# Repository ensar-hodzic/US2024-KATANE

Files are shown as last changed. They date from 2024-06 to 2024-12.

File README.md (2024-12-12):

# Keep talking and nobody explodes IRL
This is a real life game inspired by the video game called **"Keep talking and nobody explodes"**. It is a college project for the Embedded systems class. 
It uses a variety of electrical components and 2 Raspberry Pico Pi W's that communicate via MQTT. The game consists of several small challenges that have to be completed in order
to defuse the so called "bomb". But if you make a mistake you get a strike, and if you go over the maximum amount of strikes the bomb explodes. The bomb also explodes if you go over
the set time limit.

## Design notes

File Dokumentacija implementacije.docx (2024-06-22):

# Dokumentacija implementacije

# 1. Uvod

Ovaj dokument pruža tehničko objašnjenje implementacije verzije igre "Keep Talking and Nobody Explodes" na Pi Pico W platformi. Igra uključuje nekoliko mini igara koje igrači moraju riješiti koristeći različite hardverske komponente.

# 2. Arhitektura Sistema

Arhitektura sistema uključuje dva Pi Pico W koji upravljaju različitim hardverskim komponentama. Komunikacija između komponenata i kontrolera ostvaruje se pomoću GPIO pinova, a između dva Pi Pica preko MQTT veze.

## 2.1 Dijagram Arhitekture

Arhitektura sistema se sastoji od sledećih komponenti:

- 2 Pi Pico W: Glavni kontroler sistema.
- 9 Buttona: Korišćeni za različite unose u igri.
- 2 LED DOT Matrix Displeja: Prikazivanje informacija vezanih za igru.
- Sedmosegmentni Displej: Prikaz preostalog vrijemena dok bomba ne eksplodira. OVDJE ZA ŠTA
- Potenciometar: Korišten za unos analognih vrijednosti.
- Enkoder: Korišten za unos rotacionih vrijednosti.
- Matrica Tastatura: Korišćena za unos različitih sekvenci.
- 4 LED diode: Signalizacija različitih stanja igre.

# 3. Komponente Sistema

Pi Pico W master je srce sistema, zadužen za upravljanje svim komponentama i izvršavanje logike igre. Pi Pico W slave služi za dodavanje još potrebnih pinova.

## 3.1 Buttoni

Četiri buttona su povezani na GPIO pinove Pico W i koriste se za unos različitih komandi u igri. Potrebni za igre:
Button press-1
Lavirint-4
Simon says-3
Morse kod-1

## 3.2 LED DOT Matrix Displeji

Dva LED DOT Matrix displeja su povezana na Pico W i koriste se za prikazivanje različitih informacija i stanja igre. Potrebne za igru:
Button press-1
Lavirint-1

## 3.3 Sedmosegmentni Displej

Sedmosegmentni displej je korišćen za prikazivanje brojeva i povezan je na GPIO pinove.
Potrebne za igru Decode.

## 3.4 Potenciometar

Potenciometar je povezan na analogni ulaz Pi Pico W i koristi se za unos analognih vrijednosti u igri. Potrebno za igru PotenciometarGame

## 3.5 Enkoder

Rotacioni enkoder je povezan na Pi Pico W i koristi se za unos rotacionih vrijednosti. Potrebno za igr Decode.

## 3.6 Matrična Tastatura

Matrična tastatura je povezana na GPIO pinove i koristi se za unos sekvenci. Potrebno za igru Pin kod.

## 3.7 LED diode

LED diode su povezane na GPIO pinove i koriste se za signalizaciju različitih stanja igre.
Potrebno za igre:
Simon says-3
Morse-1

## 3.8 RGB Dioda

ŠTA JE RGB DIODA

# 4. Logika i Algoritmi

Glavna logika se nalazi unutar naših main programa. Pošto imamo dva Pi Pico W uređaja oni će međusobno komunicirati da znaju ukoliko je već jedna igra u toku ili ne. Razlog korištenja dva Pico W jeste taj što za implementaciju datog projekta potrebno nam je bilo više pinova nego što se nalazi na smo jednom.

## 4.1 Button

Ovaj kod implementira igru na mikrokontroleru koristeći MAX7219 LED matriks displej, taster i timer. U igri se na LED displeju prikazuje određeni broj tačkica, a korisnikov zadatak je da pritisne i drži taster onoliko sekundi koliko je tačkica prikazano. Ako korisnik pritisne taster i drži ga ispravno, sve LED tačkice se upale. Ako korisnik pogriješi u brojanju ili predugo čeka, na displeju se prikazuje znak "X". Igra koristi timer za periodično ažuriranje prikaza tačkica i provjerava korisnikov unos kako bi se utvrdilo je li tačan ili ne.

## 4.2 Decoder

Ovaj kod koristi dekoder za upravljanje brojačem koji prikazuje vrijednost na 7-segmentnom displeju. Inicijalizacija uključuje definisanje ulaznih i izlaznih pinova, postavljanje tajmera za redovno osvježavanje prikaza brojeva, i podešavanje prekida za rukovanje ulaznim signalima sa dekodera (CLK i DT pinovi). Kada se okine prekid na CLK ili DT pinu, vrijednost brojača se ažurira: CLK prekid povećava broj, dok DT prekid smanjuje broj, u zavisnosti od stanja drugog pina. Kada korisnik pritisne taster (SW pin), provjerava se da li trenutna vrijednost brojača odgovara zadatom rješenju. Ako je tako, igra se završava sa uspjehom; u suprotnom, broj grešaka se povećava. Timer periodično osvježava prikaz na 7-segmentnom displeju, prikazujući trenutnu vrijednost brojača. Cilj igre je da korisnik pomoću dekodera postigne tačan broj i potvrdi ga pritiskom na taster.

## 4.3 Lavirint

Ovaj kod implementira igru lavirinta na mikrokontroleru koristeći MAX7219 LED matrični displej, taster dugmiće i tajmere. Inicijalizacija postavlja ulazne i izlazne pinove za taster dugmiće i SPI za komunikaciju sa MAX7219. Takođe se inicijalizuje i tajmer za periodično osvježavanje prikaza igrača na displeju. Generisanje lavirinta vrši se nasumično, kreirajući staze i zidove unutar 8x8 matrice. Postoje predefinisane početne i završne tačke lavirinta. Cilj igre je da korisnik upravlja igračem pomoću tastera kako bi stigao do završne tačke lavirinta bez sudara sa zidovima. Kada igrač stigne do završne tačke, igra se završava uspešno. Klasa ima metode za prikaz igrača na displeju, reakciju na pritisak tastera za kretanje u četiri moguća pravca (gore, dole, lijevo, desno), provjeru da li je igrač stigao do završne tačke, kao i metod za završetak igre kada se završna tačka dostigne. Dodatno, postoji statička metoda za kreiranje direktne putanje od početne do završne tačke lavirinta, kao i metoda za ispis trenutnog stanja lavirinta u konzoli. Ovaj kod omogućava interaktivnu igru na mikrokontroleru, koristeći jednostavne komponente poput LED matričnog displeja i tastera, demonstrirajući upotrebu periferija i logike programiranja za igre.

## 4.4 Pin kod

Klasa MatricnaGame omogućava interaktivnu igru sa matricom tastera na mikrokontroleru. U igri korisnik treba da unese određenu šifru koristeći matricu tastera, a cilj je da unese tačnu šifru prije nego što istekne vrijeme ili da ne napravi previše grešaka. Metoda generisiSifruMatricna postavlja trenutnu šifru koju korisnik treba da unese, na osnovu trenutnog stanja (state) koje se prosljeđuje. Metoda postaviSifru je postavljena kao reakcija na prekid (IRQ) koji se aktivira kada korisnik pritisne taster na matrici. Ona obrađuje unos korisnika, provjerava da li je unijeta šifra tačna ili greška, i na osnovu toga upravlja tokom igre. Konstruktor __init__ inicijalizuje sve potrebne parametre za igru: pinove za izlaz (izlazMatricna) koji kontrolišu redoslijed aktivnih redova matrice, pinove za ulaz (ulazMatricna) koji čitaju stanje tastera, i postavlja početno stanje igre na osnovu proslijeđenog stanja. Dodatno, postoje metode solved, get_sifra i get_strikes koje vraćaju informacije o trenutnom stanju igre (da li je igra rešena, trenutna šifra, broj grešaka). Ovaj kod demonstrira upotrebu tajmera, obrade prekida, rad sa digitalnim ulazima i izlazima na mikrokontroleru kako bi se implementirala jednostavna igra sa matricom tastera.

## 4.5 Morse kod

Ovaj kod implementira sistem za prikazivanje Morseovog koda pomoću LED diode i analognog senzora. Glavna klasa je Morse, koja pruža funkcionalnost za dekodiranje i prikazivanje unaprijed definiranih poruka u Morseovom kodu na LED diodi. Klasa sadrži statičke definicije za tablicu Morseovih znakova (morse) i definira različite Morseove poruke s pripadajućim frekvencijama i dužinama impulsa (code_book). U metodi __init__, kada se instancira objekt klase Morse, definira se željena poruka prema indeksu state u code_book, te se inicijaliziraju pinovi za LED diodu i analogni senzor. Poruka se zatim konvertira u niz impulsa (svjetla ili tame) koji će se prikazivati na LED diodi prema definiranom Morseovom kodu. Objekt prati stanje modulacije pomoću tri različita vrijemenska okidača (Timer): timer za periodično prikazivanje Morseovih impulsa na LED diodi, sampler za uzorkovanje analognog signala s frekvencijom definiranom u rate, te comparator za usporedbu uzorkovanog signala s ciljnim obrascem (definiranim u target). Metoda solved() provjerava je li modulacija riješena usporedbom sadržaja buffera (uzorkovani analogni signal) s ciljnim obrascem target. Ako je modulacija riješena (tj. ako je uzorkovani signal dovoljno blizak ciljnom obrascu), deaktiviraju se svi timski okidači (timer, sampler, comparator) i postavlja se zastavica self.solved na True. Ovaj sistem omogućuje strojno dekodiranje i prikazivanje Morseovog koda, koristeći analogne senzore za detekciju svjetlosnih uzoraka, čime se simulira komunikacija putem Morseovog koda preko svjetla.

## 4.6 Potenciometar

Ovaj kod implementira jednostavnu igru s potenciometrom na mikrokontroleru. Cilj igre je detektirati određenu vrijednost potenciometra koristeći ADC interfejs za pretvorbu analognog signala u digitalni oblik. Klasa Potenciometar ima konstruktor koji inicijalizira igru postavljanjem ciljane vrijednosti potenciometra, koja je unaprijed definirana u listi potencimetar_values. Ovisno o odabranom state parametru, odabire se odgovarajuća ciljna vrijednost. Igra koristi ADC objekt za čitanje trenutne vrijednosti s potenciometra, koji je spojen na određeni pin na mikrokontroleru. Timer (timerPot) se koristi za periodično izvršavanje funkcije PotenciometarGame, koja provjerava trenutnu vrijednost potenciometra. U metodi PotenciometarGame, trenutna vrijednost potenciometra se uspoređuje s ciljnom vrijednosti self.sifra. Ako je apsolutna razlika između očitane vrijednosti i ciljne vrijednosti manja od zadane tolerancije (eps), igra se riješava. Timer se zaustavlja, a zastavica self.solved postavlja na True, što označava da je igra završena uspješno. Metoda solved omogućuje vanjskom kodu da provjeri je li igra riješena, dok get_sifra vraća ciljanu vrijednost potenciometra za referencu ili prikaz korisniku. Ovaj sistem omogućuje jednostavno i automatizirano praćenje i rješavanje igre s potenciometrom, što može biti korisno u edukativnim ili demonstracijskim svrhama za učenje o radu s analognim senzorima i digitalnim sučeljima mikrokontrolera.

## 4.7 Simon says

Ovaj kod implementira igru "Simon Says" na mikrokontroleru, simulirajući igru u kojoj korisnik mora ponoviti uzorak paljenja i gašenja LED-ica prema predefiniranoj sekvenci. Klasa SimonSays ima konstruktor koji inicijalizira igru s dva lista pinova: button_pins za tastere koji se koriste za unos, i led_pins za LED-ice koje će se paliti i gasiti. Također prima listu code koja definira sekvencu koju korisnik mora ponoviti. LED-ice i tasteri inicijaliziraju se kao Pin objekti s odgovarajućim ulaznim (Pin.IN) I izlaznim (Pin.OUT) postavkama. code lista čuva sekvencu koju treba pogoditi. Za svaki taster postavlja se prekid (irq) koji reagira na uzlaznu (rising) promjenu signala, pozivajući button_handler metodu za obradu pritiska tastera. Implementirana je i debouncing logika kako bi se izbjegli lažni prekidi prilikom pritiska.
Periodični tajmeri (Timer) se koriste za upravljanje igrom:

- show_timer periodično pokreće funkciju turn_on_led kako bi se prikazala sekvencija svjetlosnih signala korisniku.
- prikazujSekvencu tajmer se koristi za periodično prikazivanje cijele sekvence LED-ica, s pauzama između sekvenci.

Metoda turn_on_led upravlja redoslijedom paljenja i gašenja LED-ica prema definiranoj sekvenci. Svaka LED-ica se pali i gasi prema trenutnom indeksu u code listi, omogućujući vizualno prikazivanje sekvence korisniku. Metoda checkInput provjerava unos korisnika nakon što je završena prikazana sekvencija. Ako korisnik ispravno ponovi sekvencu, ispisuje igra se završava i sve LED-ice se upale. Ako se pogriješi, korisniku se omogućuje ponovni pokušaj, a broj pogrešaka se povećava. Metoda ShowFailure koristi se za vizualni efekt u slučaju pogrešnog unosa, gdje se LED-ice brzo pale i gase kako bi signalizirale grešku prije ponovnog pokušaja. Ovaj kod pruža interaktivno iskustvo igre "Simon Says" na mikrokontroleru, koristeći LED-ice i tastere za unos, što omogućuje praktičnu primjenu u obuci ili demonstracijama za rad s digitalnim ulazima i izlazima.

## 4.8 Wirecutter

Klasa WireCutter simulira sistem za rezanje žica na mikrokontroleru. Inicijalizira se s izlaznim i ulaznim pinovima te listom pinova koji se smiju rezati. Parametar inOrder određuje redoslijed rezanja žica. Svi pinovi se inicijaliziraju kao objekti Pin za odgovarajuće ulazne ili izlazne funkcije. Izlazni pinovi se inicijalno postavljaju na on(). Tajmer timer periodično poziva funkciju CheckWires svakih 100 ms, koja provjerava stanje žica i detektira događaje na ulaznim pinovima. Svaki ulazni pin ima postavljen prekid (irq) na padajući rub signala, što aktivira metodu CheckWires za daljnju provjeru. Tajmer checker također periodično poziva funkciju checkSolved svakih 100 ms, koja provjerava jesu li sve žice označene u valid_to_cut listi već rezane. Metoda CheckWires upravlja logikom rezanja žica: provjerava redoslijed i ispravnost te bilježi pogreške ako žice nisu rezane prema očekivanjima. Metoda checkSolved provjerava jesu li sve žice iz valid_to_cut već rezane i postavlja zastavicu solved na True ako jesu. Ovaj kod pruža simulaciju upravljanja i praćenja rezanja žica na mikrokontroleru, koristeći digitalne ulaze i izlaze te periodično provjeravanje stanja sistema.

## 4.9 Pico W slave

Pico W slave uređaj inicijalizira globalne varijable za praćenje stanja igre, spremnosti (main_ready), trenutnog stanja (state) i izvršavanja igre (run). Definira i pinove za različite komponente: tipke i LED diode za igru Simon Says, matricu tastatura, potenciometar, pinove za Morseov kod, pin za igru s tasterom i pinove za igru s žicama. Pomoćna funkcija subscribe obrađuje MQTT poruke: postavlja main_ready kada je uređaj spreman, ažurira state kada stignu poruke o stanju igre, te zaustavlja igru na poruke o završetku igre ("win" ili "lose"). Funkcija check periodično provjerava stanje modula u igri, broji riješene module i prati greške. Informacije o broju grešaka i riješenim modulima šalje putem MQTT-a. Nakon uspostave Wi-Fi veze i MQTT klijenta, program čeka da glavni uređaj označi spremnost (main_ready). U glavnoj petlji čeka da glavni uređaj pokrene igru slanjem odgovarajuće MQTT poruke (run). Moduli igre se inicijaliziraju kao objekti različitih klasa (SimonSays, MatrixGame, Potenciometar, Morse, Button, Wires) s odgovarajućim parametrima. Glavni tajmer je postavljen da periodično poziva funkciju check kako bi pratio stanje igre tokom trajanja. U glavnoj petlji programa ispisuje se "game is running..." i čeka se signal o trajanju igre putem MQTT-a.

## 4.10 Pico W master

Pico W master uređaj koordinira upravljanje stanjem igre, komunikaciju putem MQTT-a i procese donošenja odluka. Ovisi o Pico W slave uređaju za dodatne GPIO pinove kako bi se komuniciralo s različitim komponentama igre. Slave uređaj rukuje specifičnim interakcijama u igri i šalje svoje stanje i napredak natrag master uređaju putem MQTT-a. Ova podjela zadataka omogućava distribuiranu obradu i efikasno upravljanje složenom logikom igre preko više uređaja. Pico W master uređaj inicijalizira globalne varijable za upravljanje stanjem igre i komunikaciju s drugim uređajima putem MQTT protokola. Navode se i pinovi koje Pi Pico W koristi za povezivanje s komponentama poput labirintskih tipki, displeja, enkodera i segmentnog displeja. Pomoćne funkcije uključuju subscribe, koja prati MQTT poruke za ažuriranje globalnih varijabli o prisustvu drugih igrača i stanju igre. Funkcija rgb_randomiser generira slučajne RGB vrijednosti za vizualne efekte ili indikacije u igri. Funkcija explode aktivira se kada igra završi zbog prekoračenja dozvoljenog broja grešaka ili rješenja svih modula. Zaustavlja glavni tajmer i šalje poruku "lose" putem MQTT-a. Funkcija check periodično provjerava riješene module i broj grešaka za donošenje odluke o završetku igre (pobjeda ili poraz). Funkcija publish_state objavljuje trenutno stanje igre putem MQTT-a, uključujući riješene module i maksimalan broj dopuštenih grešaka. Nakon postavljanja Wi-Fi veze i MQTT klijenta, program čeka registraciju slave uređaja i aplikacije na telefonu prije početka glavne igre. U glavnoj petlji igre, program inicijalizira početno stanje i maksimalan broj grešaka, periodično provjerava stanje igre sve dok se ne završi.

# 5. Zaključak

Ova dokumentacija pruža pregled ključnih tehničkih aspekata implementacije verzije igre "Keep Talking and Nobody Explodes" na Pi Pico W platformi. Detaljniji uvidi su dostupni u izvornom kodu projekta.

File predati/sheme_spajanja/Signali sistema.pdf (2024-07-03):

Signal | Tip | Opis
Pritisak tastera na tastaturi | Digitalni Ulaz | Registruje se pritisak na tastaturi adekvatno, i svaki 4 pritisak izaziva poređenje sa šifrom
Prozivka tastature | Digitalni Izlaz | Kada želimo provjeriti pritisak na nekom redu postavljamo adekvatni pin na HIGH.
Pritisak tastera za Button game | Digitalni Ulaz | Registruje se pritisak na taster i sve dok je pritisnut na LED displeju se prikazuje više i više tački. Kada se taster oslobodi vrši se poređenje broja prikazanih tačaka i ciljanog broja.
8x8 LED Displej | Digitalni Izlaz | Vršimo prikaz tački na 8x8 displeju. Komunikacija se vrši putem SPI. Ako je taster držan tačan broj sekundi onda se ekran potpuno potpunu, ako se desila greška prikazujemo “X”, inače je displej prazan.
Pritisak tastera za Simon Says | Digitalni Ulaz | Ako je taster pritusnut u vremenskom intervalu van prikaza LEDica, on će se registrovati. Svaki peti taster izaziva poređenje sa prikazanom sekvencom.
LEDice Simon Says | Digitalni Izlaz | Prikaz sekvence za simon says. Ako je modul riješen upaliti sve ledice.
Pritisak tastera za Labirint | Digitalni Ulaz | Svaki taster označava jednistven smjer kretanja u Labirintu, i njegovim pritiskom će se promijeniti pozicija igrača, ako je ot moguće, a ako bi igrač udario u zid labirinta on ostaje na mjestu i broj greški se inkrementira
8x8 LED Displej | Digitalni Izlaz | Displej prikazuje poziciju igrača trenutnu kao trepćuća

| | tačka, dok se izlaz prikazuje kao ispunjena tačka. Kada je labirint riješen ne treba ništa prikazati.
Pritisak Enkodera | Digitalni Ulaz | Pritiskom rotacionog enkodera se treba izvršiti poređenje brojača sa šifrom.
Pomjeranje Enkodera | Digitalni Ulaz | Pomjereanjem rotacionog enkodera se brojač inkrementira ili dekrementira u ovisnosti od smjera.
7seg Displej | Digitalni Izlazi | Prikaz trenutne vrijednosti brojača na displeju.
RGB dioda | Digitalni Izlaz | Prikaz stanja igre.

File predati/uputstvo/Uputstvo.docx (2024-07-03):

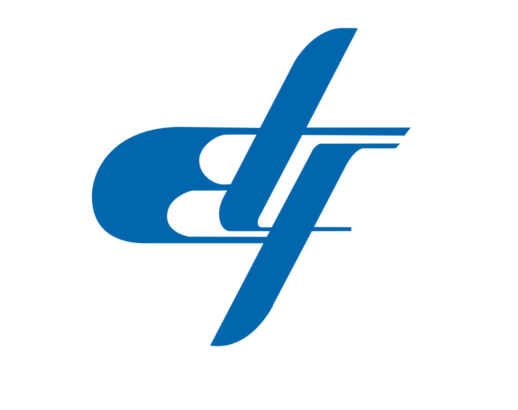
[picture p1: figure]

KAKO ZAUSTAVITI BOMBU???

UPUTSTVO ZA “KEEP TALKING AND NOBODY EXPLODES”

# 1. Sadržaj

# 2. O igri

Igra se sastoji od 2 igrača,jedan koji ima bombu pred sobom (deaktivator bombe)i drugi koji ima uputstvo (stručnjak).

Igrači imaju 3 minute da deaktiviraju bombu. Bomba se sastoji od 5 modula koji se moraju riješiti ispravno na način koji je opisan u uputstvu kako bi se bomba deaktivirala. Broj dozvoljenih grešaka je nasumičan između 0 i 3 i prikazan je na MQTT panelu.Ukoliko pređete preko dozvoljenog broja grešaka, igra završava.

Sretno!

# 3. Kako pokrenuti igru?

Potrebno je provjeriti postavke za konekciju na WiFi mrežu za naša dva mikrokontrolera unutar bombe. Oba mikrokontrolera je potrebno spojiti na računar i promijeniti postavke konekcije u config.py file-ovima. Također po potrebi promijeniti MQTT broker na neki po vašoj želji. Nakon toga se mogu priključiti oba mikrokontrolera na neki izvor napajanja.

Sljedeći korak jeste postaviti MQTT panele na nekoj MQTT Dashboard aplikaciji. Ukoliko želite koristiti naš kreirani panel, skinite aplikaciju IoT MQTT Panel (https://play.google.com/store/apps/details?id=snr.lab.iotmqttpanel.prod&hl=en), i u opciji Backup/Restore, restorati file pod imenom “KataneMQTTPanel.json”, i može se početi igrati.

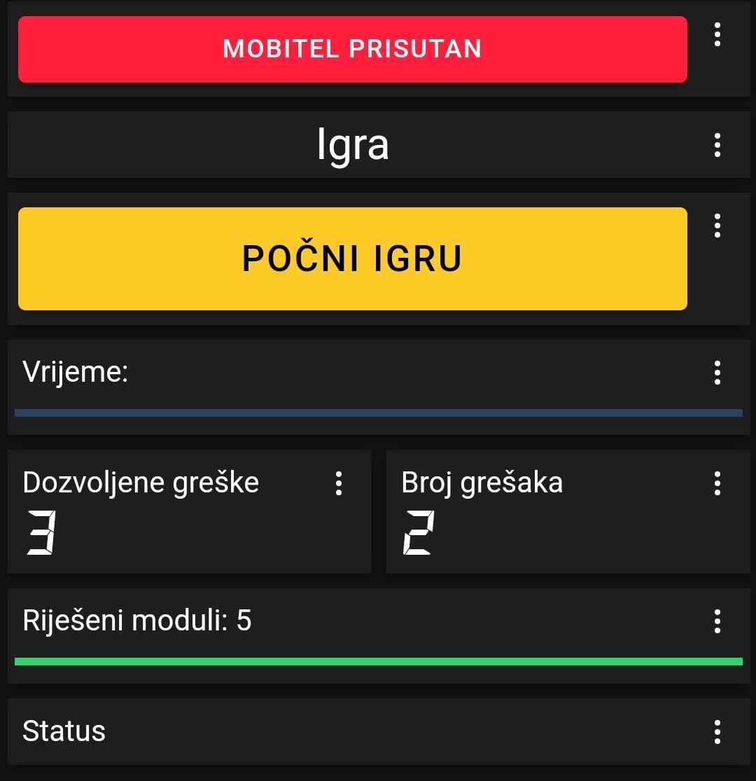
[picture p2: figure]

Topic | Tip | Payload | Opis
katane/app_present | Button | 1 | Prisutnost mobitela
katane/game_start | Button | 1 | Početak igre
katane/game_over | Text | | Kraj igre
katane/strikes | Text | | Broj grešaka
katane/solved | Text | | Broj riješenih modula
katane/game_state | JSON | max_strikes | Broj dozvoljenih grešaka
katane/time | Text | | Potrošeno vrijeme

Ukoliko ne želite koristiti naš panel, potrebno se pretplatiti na sljedeće topic-e.

Da bi započeli samu igru, potrebno je priključiti mikrokontrolere na izvor napajanja (kompjuter, powerbank, i sl.). Sačekati malo vremena da se spoje na mrežu. Na telefonu prvo je potrebno pritisnuti da dugme “Mobitel prisutan”i tek onda može se kliknuti dugme “Počni igru” kako bi igra počela.

# 4. MODULI

## 4.1 Modul: Simon Says

Modul se sastoji od 3 LED i 3 tipke, kako bi riješili ovaj modul, morate odigrati igru “Simon says”, što u biti znači da pratite šta god LED kažu da pritisnete. Pogriješite li sekvencu, napravili ste prekršaj.Ne možete unositi sekvencu dok se prikazuje.

## 4.2 Modul: Taster

Modul se sastoji od tastera i matrix displeja. Kako bi riješili ovaj modul, potrebno je pritisnuti i držati taster dok se odgovarajući broj tačaka na displeju ne pojavi. Uspješno rješavanje znači da je displej popunjen, dok neuspjeh se označi sa slovom X na displeju, i naravno još jednim promašajem. Odnos boje i broja tačaka se nalazi u tabeli ispod:

Boja | Broj tačaka
Nijedna | 2
Crvena | 3
Plava | 4
Ljubičasta | 5
Zelena | 6
Žuta | 7
Cyan | 8
Bijela | 9

## 4.3 Modul: Lavirint

Modul se sastoji od 4 tastera i matrix displeja. Kako bi riješili ovaj modul, potrebno je kretati se kroz lavirint dok se ne stigne do cilja. Tačka koja treperi predstavlja trenutnu poziciju. Drugi igrač govori prvom kuda da se kreće. Slike labirinta u odnosu na boju su ispod.

Boja | Lavirint

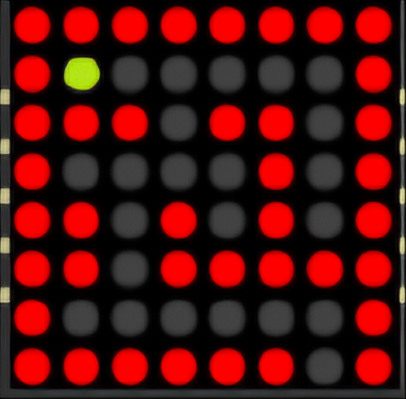
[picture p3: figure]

Nijedna

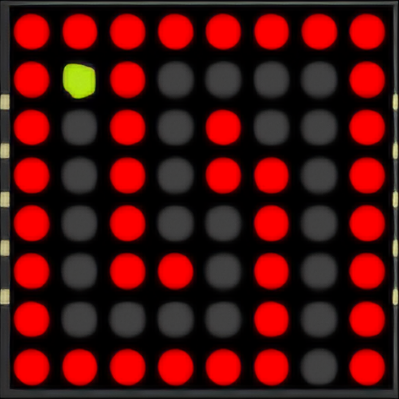
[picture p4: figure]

Crvena

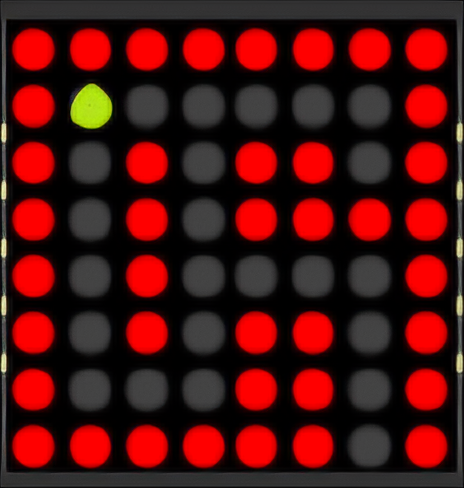
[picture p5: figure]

Plava

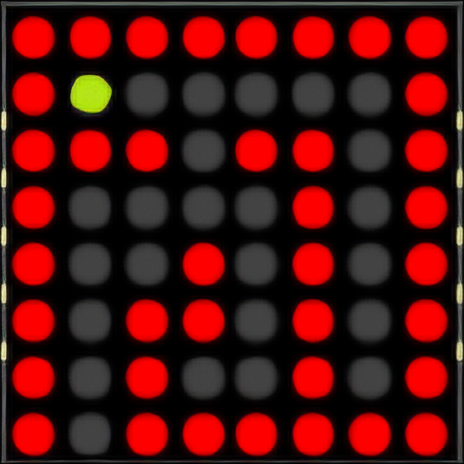
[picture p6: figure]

Ljubičasta

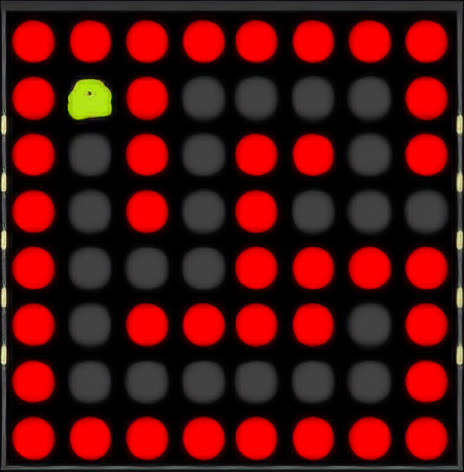
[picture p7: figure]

Zelena

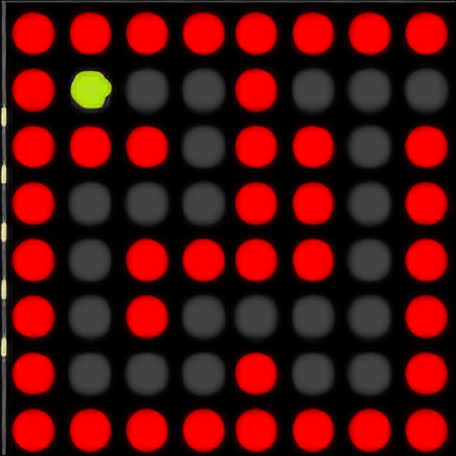
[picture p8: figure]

Žuta

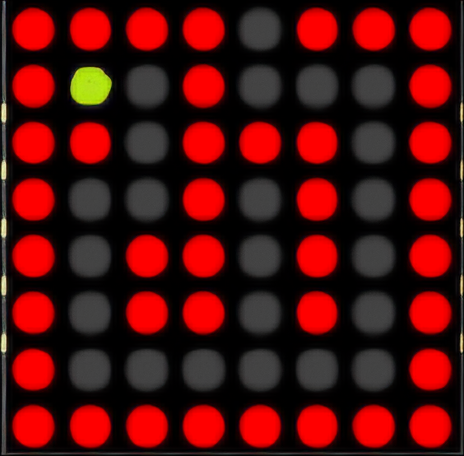
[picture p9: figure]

Cyan

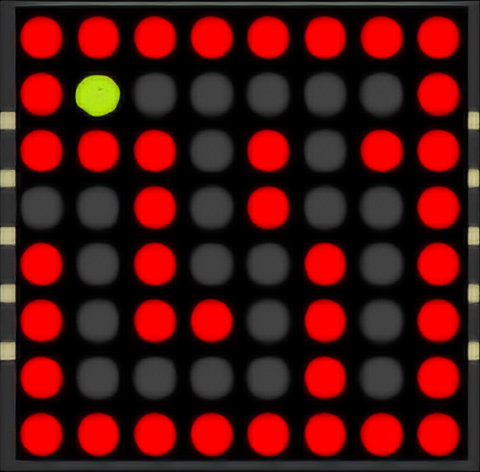
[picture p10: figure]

Bijela

## 4.4 Modul: Dekoder

Modul se sastoji od sedmosegmentnog displeja i rotacionog enkodera. Potrebno je odabrati tačnu vrijednost pomoću enkodera i potvrditi je pritiskom na enkoder.Tabela tačnih vrijednosti se nalazi u tabeli ispod:

Boja | Vrijednost
Nijedna | 17
Crvena | 73
Plava | 29
jubičasta | 31
Zelena | 7
Žuta | 20
Cyan | 47
Bijela | 97

## 4.5 Modul: Šifra

Modul se sastoji od matrične tastature na kojoj je potrijebno unijeti tačnu šifru na osnovu boje dioda sa strane bombe. Tabela šifri se nalazi ispod:

Boja | Šifra
Nijedna | 0000
Crvena | 1234
Plava | 1987
Ljubičasta | 5397
Zelena | 3973
Žuta | 8892
Cyan | 4911
Bijela | 8603

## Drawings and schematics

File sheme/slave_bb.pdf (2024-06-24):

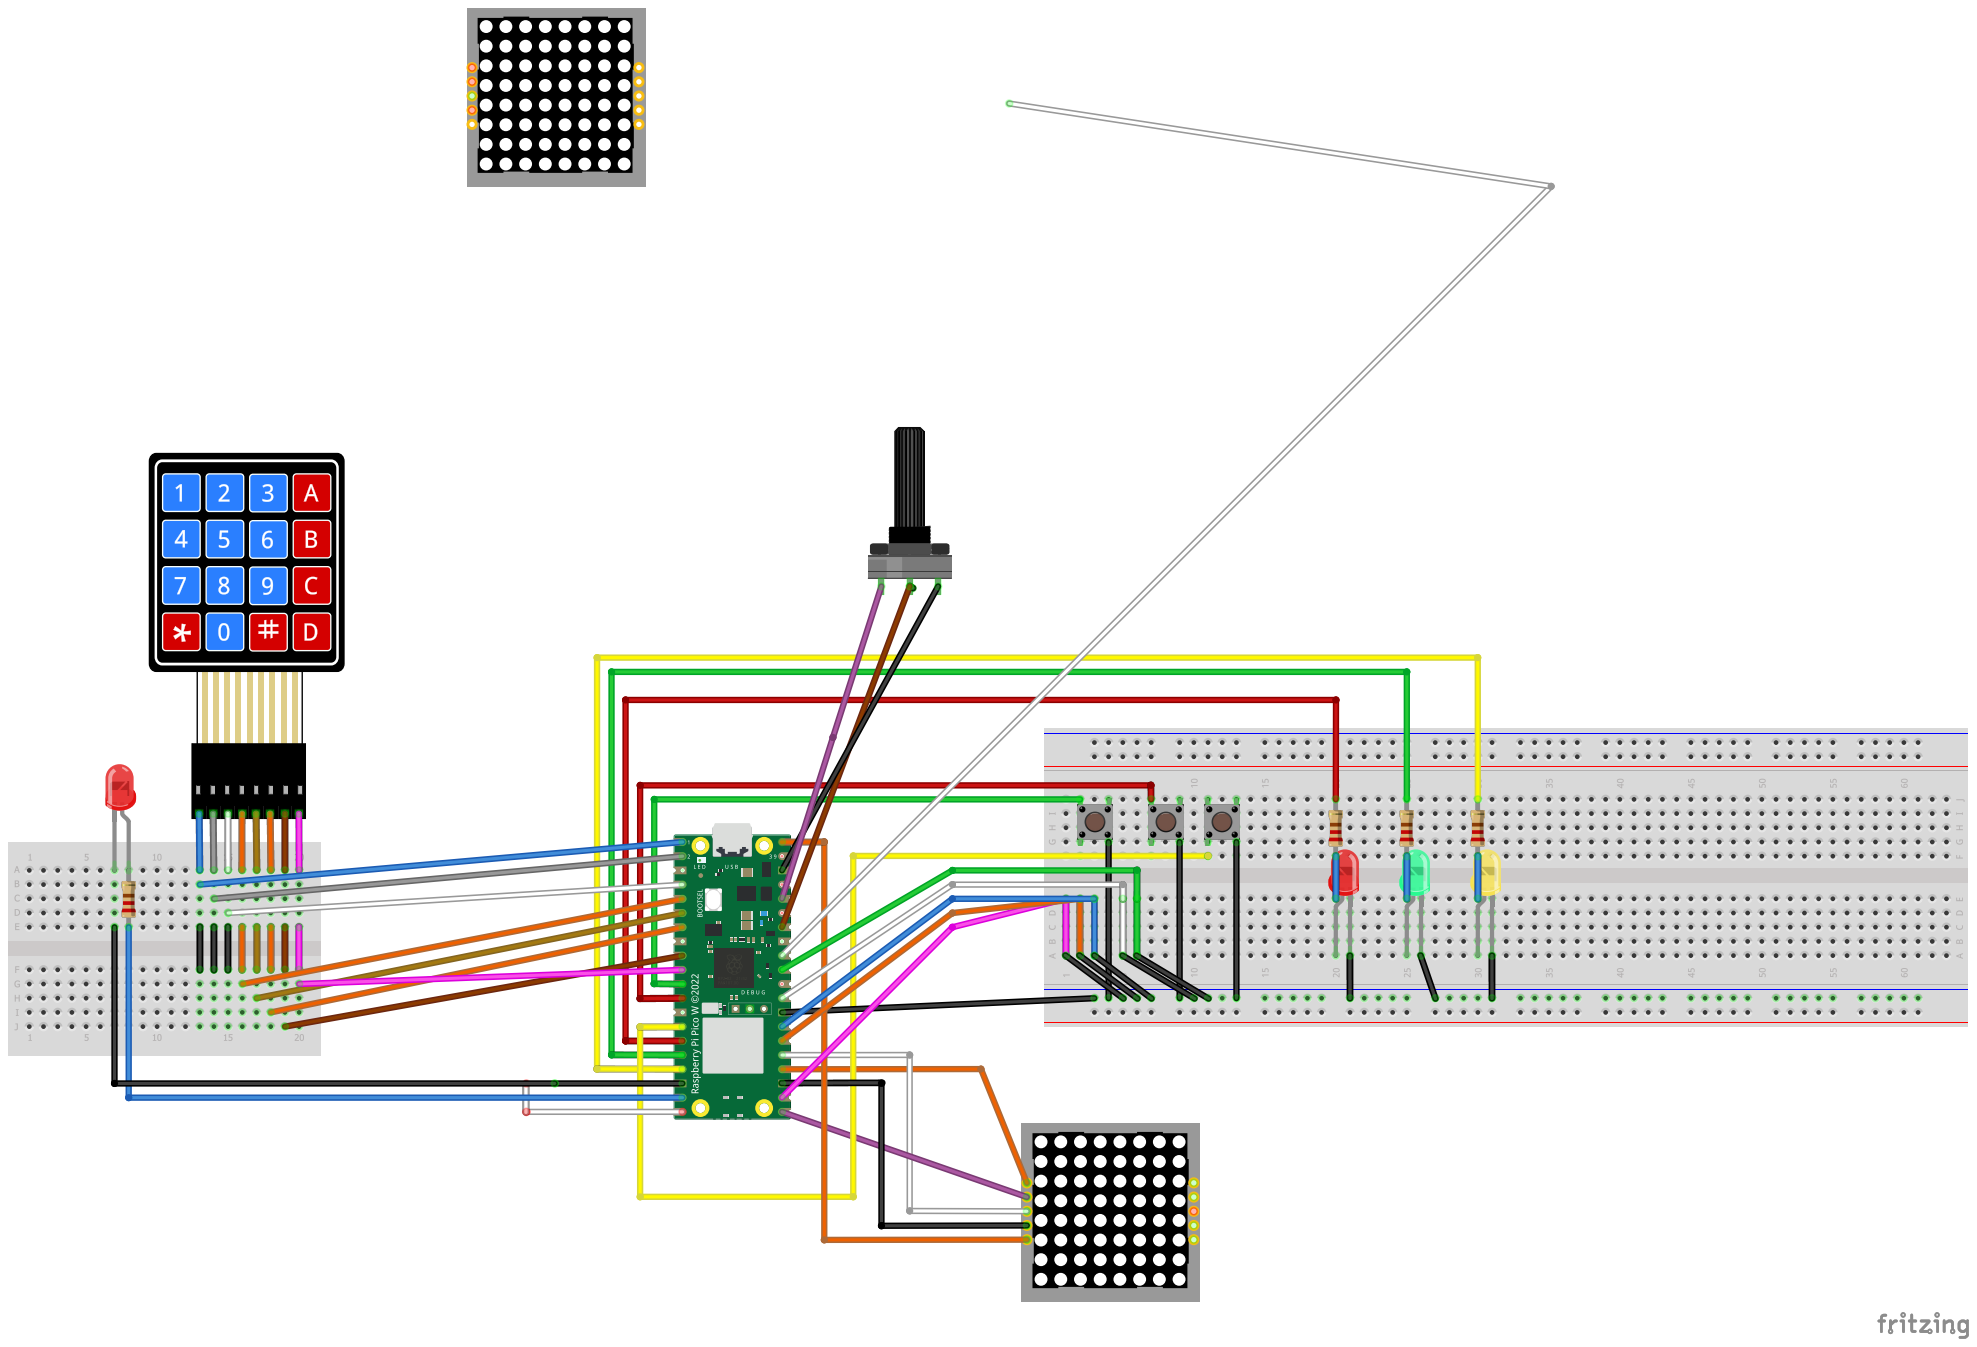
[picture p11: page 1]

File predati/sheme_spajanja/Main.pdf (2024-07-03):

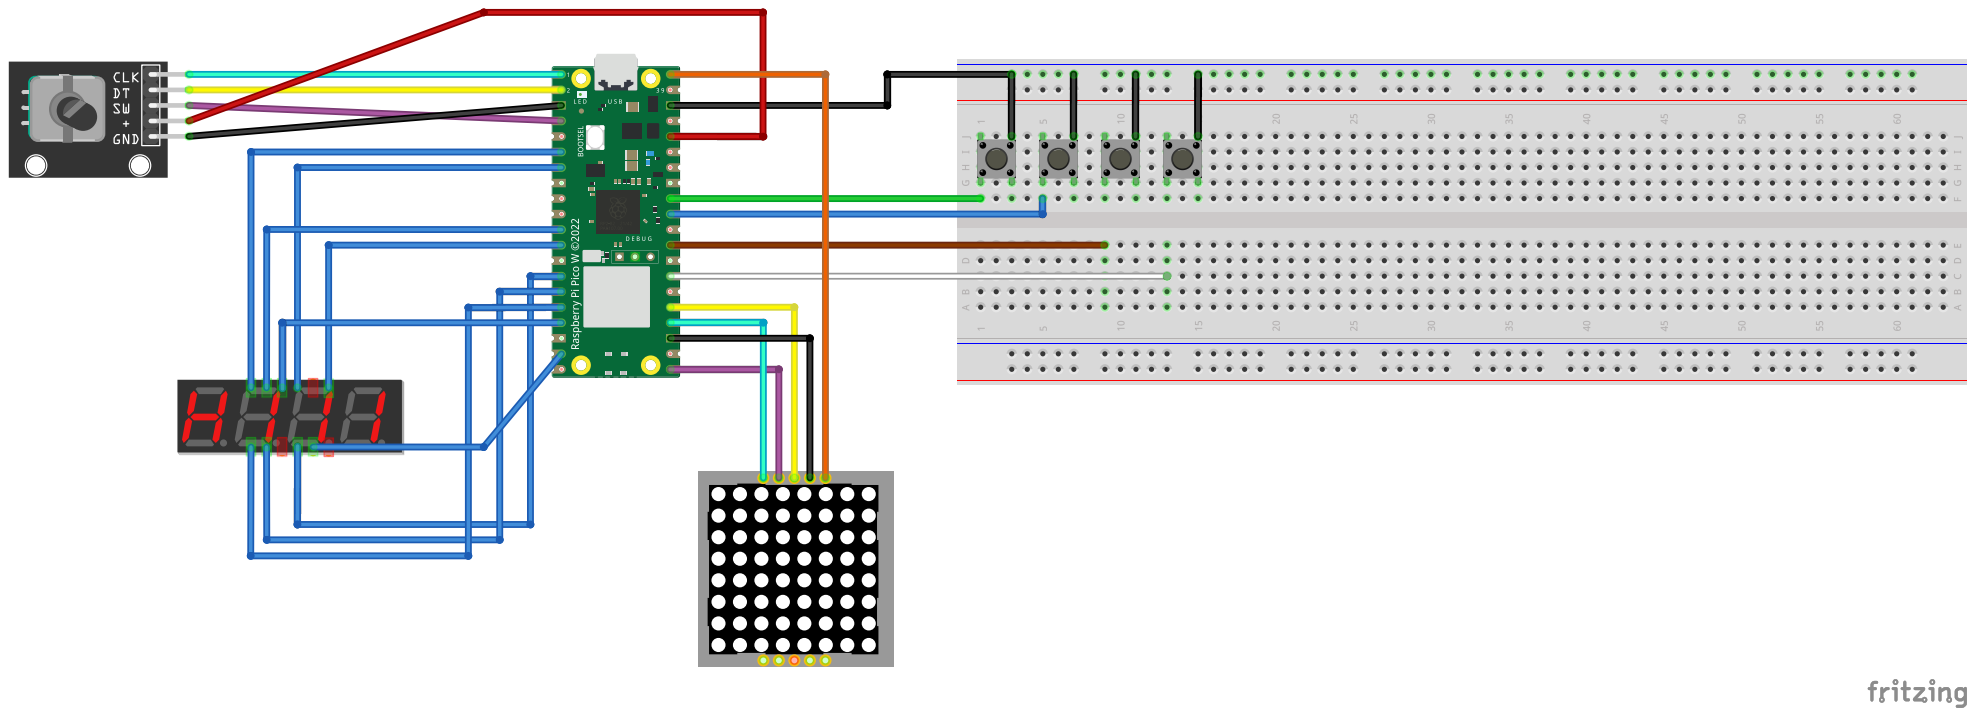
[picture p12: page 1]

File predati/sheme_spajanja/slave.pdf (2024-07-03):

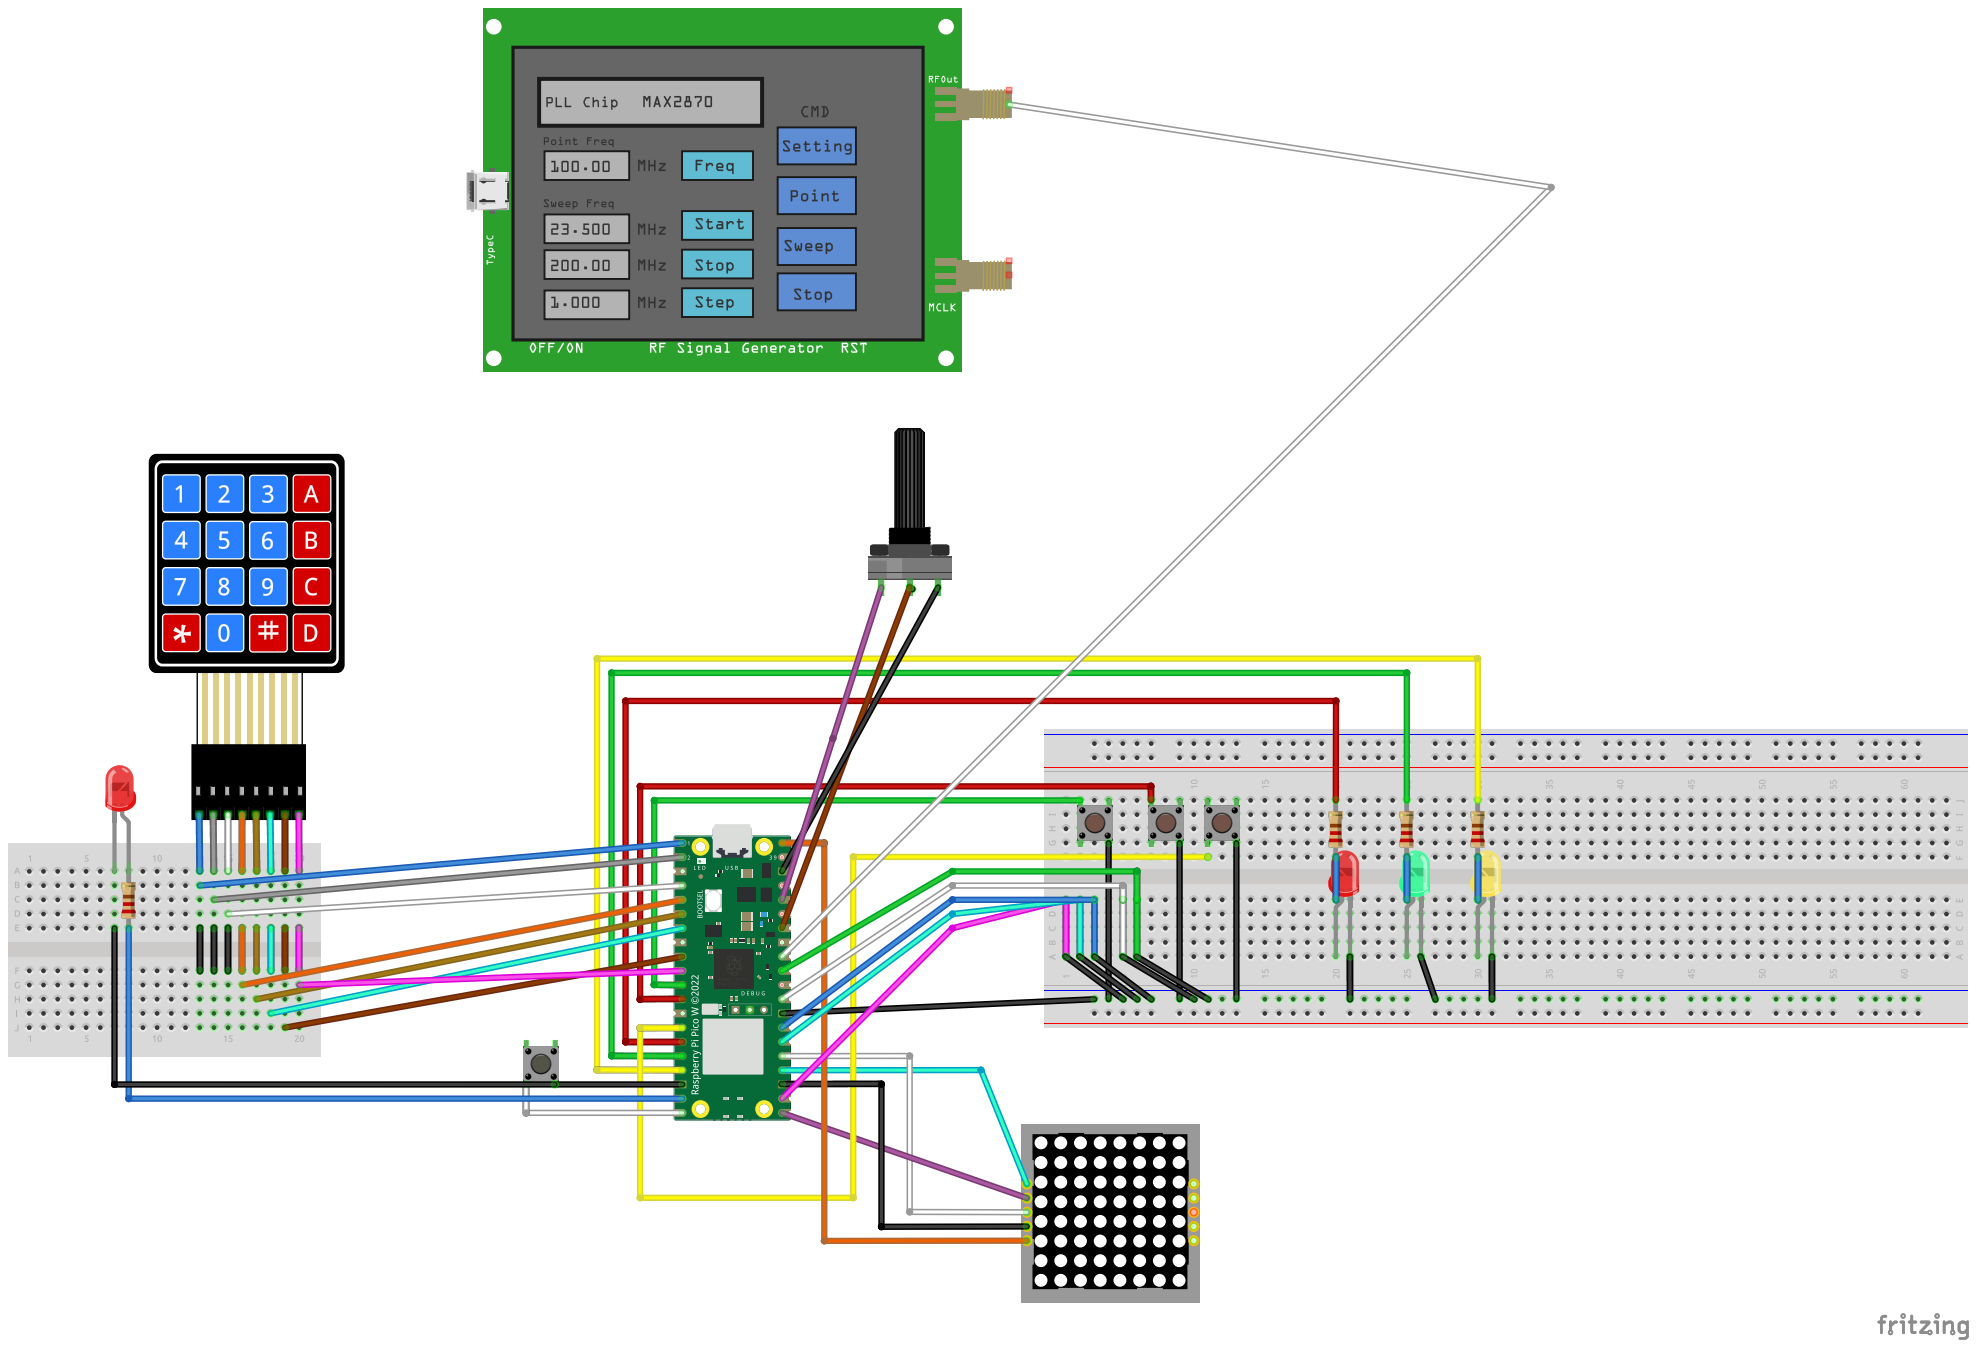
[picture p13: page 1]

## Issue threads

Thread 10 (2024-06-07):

Button press

nbanda1, 2024-06-07:
Slave Pico
8x8 matrix LED - 3 PIN-a
Switch- 1 PIN
Drži switch dok se ne napuni određen broj žica.

lilhast1, 2024-06-12:
Testiranje neuspjesno.

Closed 2024-06-26.

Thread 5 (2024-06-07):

Simon says

nbanda1, 2024-06-07:
Slave Pico
Napisati modul simon says.
3 switch-a i 3 LED-a.

lilhast1, 2024-06-12:
Prepraviti kod da:
1. Uspori prikaz sekvence
2. Vrsi prikaz sekvence sve dok modul nije rijesen

Closed 2024-06-26.

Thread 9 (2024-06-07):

Modul lavirint

ensar-hodzic, 2024-06-07:
Master pico, 4 switcha za UP DOWN LEFT RIGHT, pogrešan unos dovodi do faila modula.

lilhast1, 2024-06-12:
Prepraviti kod da postuje specifikaciju iznad navedena.

Closed 2024-06-24.

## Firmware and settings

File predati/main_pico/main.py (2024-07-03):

from machine import Pin,Timer
import time
from umqtt.robust import MQTTClient
import ujson
from labirint import Labirint
from decoder import Decoder
import random
import network
import time
import gc
gc.enable()

#___________________________________Glob varijable______________________________________________#
slave_present = False
app_present = False
game_start = False
solved = 0 	
strike = 0
solved_slave = 0
strike_slave = 0
main_timer = Timer(-1)
game_running = False
spam_slave = Timer(-1)
TIME = 0
MAX_TIME = 180
MODULI_CNT = 5
SERVER = '192.168.43.69' # broker
network_name = "IME_MREZE"
network_password = 'SIFRA_MREZE'
#___________________________________Pinouts_____________________________________________________#
labirint_pins = [27,26,22,21] # tasteri labirinta lijevo, gore, dole, desno
display_pins = [0, 18,19,16] # labirint display: spi, SCK, MOSI, CSm
encoder_pins = [0,1,2] # jasno clk, dt, sw
segmenti = [4,	5] # odabir cifre
digits = [8,9,10,11,12,13,14] # segmenti na cifri
rgb = [3,17,28]

#___________________________________Pomocne funkcije____________________________________________#
topics = [b'katane/slave_present' , b'katane/app_present', b'katane/game_start',b'katane/slave_solved', b'katane/finalhandshake',b'katane/slave_strike']
def subscribe(topic, msg):
	global slave_present, app_present, game_running, game_start, strike_slave, solved_slave, spam_slave
	print(topic.upper())
	if topic == b'katane/slave_present' and msg == b'1':
		slave_present = True
	if topic == b'katane/app_present' and msg == b'1':
		app_present = True
	if topic == b'katane/game_start' and msg == b'1':
		game_running = True
		game_start = True
	if topic == b'katane/slave_solved':
		solved_slave = int(msg)
	if topic == b'katane/slave_strike':
		strike_slave = int(msg)
		print("slave strike ", strike_slave)
	if topic == b'katane/finalhandshake':
		spam_slave.deinit()

# postavlja rgb i vraca dozvoljeni broj strikeova i stanje igre
def rgb_randomiser():
	state = random.randint(0, 7) 
	strikes = random.randint(0,3)
	ledice = [Pin(i, Pin.OUT) for i in rgb]
	mask = 1
	for led in ledice:
		led.value(state & mask)
		mask = mask << 1

	return state, strikes

def explode(t):
	global game_running, mqtt_conn, main_timer
	mqtt_conn.publish(b'katane/game_over', b'BOOM')
	main_timer.deinit()
	game_running = False

def check(t):
	global solved, strike, game_running
	mqtt_conn.check_msg()
	new_solved = solved_slave
	new_strike = strike_slave
	for m in moduli:
		new_solved += int(m.solved)
		new_strike += m.get_strikes()
	if new_strike > max_strike:
		explode(t)
		print("previse gresaka")
	elif new_solved  == MODULI_CNT:
		count_down.deinit()
		print('pobjeda')
		mqtt_conn.publish(b'katane/game_over', b'Bomba je deaktivirana')
		main_timer.deinit()
		game_running = False
	if new_strike != strike:
		strike = new_strike
		mqtt_conn.publish(b'katane/strikes', str(strike).encode('ascii'))
	if new_solved != solved:
		solved = new_solved
		mqtt_conn.publish(b'katane/solved', str(solved).encode('ascii'))

def publish_state(state, max_strike):
	json = '{ "state": ' + str(state) + ',"max_strike": ' + str(max_strike) + ' }'
	mqtt_conn.publish(b'katane/game_state', json.encode('ascii'),1)
	mqtt_conn.publish(b'katane/solved', b'0')
	mqtt_conn.publish(b'katane/strikes', b'0')
	mqtt_conn.publish(b'katane/game_over', b'Igra u toku')

def post_time(t):
	global TIME
	mqtt_conn.publish(b'katane/time', str(TIME).encode('ascii'))
	TIME += 1

#___________________________________Spajanje na Wifi____________________________________________#

nic = network.WLAN(network.STA_IF)
nic.active(True)
nic.connect(network_name, network_password)




while not nic.isconnected():
    print('Cekam vezu')
    time.sleep(1)
print("spojeno")

print(nic.ifconfig())
#___________________________________Game setup____________________________________________#


mqtt_conn = MQTTClient(client_id='2', server=SERVER,user='',password='',port=1883)


mqtt_conn.set_callback(subscribe)

mqtt_conn.connect()
print('Uspjesno se nasao broker')


for topic in topics:
    mqtt_conn.subscribe(topic,1)


while not slave_present:
	print('cekam slave da se javi')
	mqtt_conn.wait_msg()

print("dalje")
while not app_present:
	print('cekam aplikaciju sa telefona da se javi')
	mqtt_conn.wait_msg()

mqtt_conn.publish(b'katane/main_ready', b'1') # javi telefonu da je main spreman da pocne

while not game_start:
	mqtt_conn.wait_msg()
	print('cekam da telefon kaze da igra pocinje')

#____________________________________Game Run_______________________________________#

state, max_strike = rgb_randomiser()

publish_state(state, max_strike) # javi slaveu stanje, a telefonu broj dozvoljenih pokusaja


count_down = Timer(period= MAX_TIME * 1000 , mode=Timer.ONE_SHOT, callback=explode)

moduli = [Labirint( labirint_pins, display_pins,state),
          Decoder(encoder_pins,  segmenti,digits, state)]
main_timer.init(period=500, mode=Timer.PERIODIC, callback=check)
cdtimer = Timer(period=1000, mode = Timer.PERIODIC, callback=post_time)
while game_running:
	print('igra u toku...')
	time.sleep(0.5)


for m in moduli:
    m.deinit()
    
cdtimer.deinit() 

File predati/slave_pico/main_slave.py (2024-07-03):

from machine import Pin, Timer
import time
import network
from umqtt.robust import MQTTClient
import ujson
from simonsays import SimonSays
from matricna import MatricnaGame
from button import Button


#___________________________________Glob varijable______________________________________________#
main_ready = False
state = 0
strikes = 0
solved = 0
run = False
main_timer = Timer(-1)
network_name = "IME_MREZE"
network_password = 'SIFRA_MREZE'
SERVER='192.168.43.69' # mqtt broker
#___________________________________Pinouts_____________________________________________________#

simon_buttons = [8, 9, 10]
simon_leds = [11, 12, 13]
pins_izlazna = [0, 1, 2, 3] # za matricnu tastaturu
pins_ulazna = [4, 5, 6, 7] # mislim da su ovo redovi po sjecanju
pin_potenciometar = [28]
morse_pins = [14, 27] # jedna ledica za morse kod prikaz i ulaz signala
button_game_pins = [15] # jedno dugme, button zauzima vec ss=16, sck=18, mosi=19!
wire_pins = [17, 20, 21, 22, 26] # sta god ali 5
topics = [b'katane/main_ready',b'katane/game_state',b'katane/game_over']
#___________________________________Pomocne funkcije____________________________________________#
def subscribe(topic, msg):
	global run, main_ready, state, main_timer, spammer
	if topic == b'katane/main_ready' and msg == b'1':
		main_ready = True
		spammer.deinit()
	if topic == b'katane/game_state' and main_ready:
		parsed = ujson.loads(msg)
		print(msg)
		state = int(parsed["state"])
		run = True
		print(run)
	if topic == b'katane/game_over' and msg in (b'Bomba je deaktivirana', b'BOOM'):
		main_timer.deinit()
		run = False

def check(t):
	global moduli_pool, strikes, solved, solved_moduli
	
	new_strikes = 0
	new_pool = []

	for m in solved_moduli:
		new_strikes += m.get_strikes()
	for m in moduli_pool:
		new_strikes += m.get_strikes()
		if m.solved:
			solved_moduli.append(m)
		else:
			new_pool.append(m)

	moduli_pool = new_pool
	print(f'strikes: {strikes} new: {new_strikes}')
	print(f'solved: {solved} new: {len(solved_moduli)}')
	if strikes != new_strikes:
		strikes = new_strikes
		mqtt_conn.publish(b'katane/slave_strike', str(strikes).encode('utf-8'))
	if solved != len(solved_moduli):
		solved = len(solved_moduli)
		mqtt_conn.publish(b'katane/slave_solved', str(solved).encode('utf-8'))

def spam(t):
	mqtt_conn.publish(b'katane/slave_present', b'1')
#___________________________________Spajanje na Wifi____________________________________________#


nic = network.WLAN(network.STA_IF)
nic.active(True)
nic.connect(network_name, network_password)

while not nic.isconnected():
    print('Cekam vezu')
    time.sleep(1)
print("Spojeno")
print(nic.ifconfig())
#___________________________________Game setup____________________________________________#

mqtt_conn = MQTTClient(client_id='Pacacalave', server=SERVER,user='',password='',port=1883)

mqtt_conn.set_callback(subscribe)

mqtt_conn.connect()
for topic in topics:
	mqtt_conn.subscribe(topic,1)

spammer = Timer(period=100, mode=Timer.PERIODIC, callback=spam)

print("SPOJENO NA MQTT")
while not main_ready:
	mqtt_conn.publish(b'katane/slave_present', b'1')
	print('cekam main da se javi da je ziv')
	mqtt_conn.wait_msg()
		

while not run:
	print('cekam informacije o igri...')
	mqtt_conn.wait_msg()
	time.sleep(0.1)


mqtt_conn.publish(b'katane/finalhandshake',b'1')
spammer.deinit()


moduli_pool = [SimonSays(simon_buttons, simon_leds),
				MatricnaGame(state, pins_izlazna, pins_ulazna),
				Button(state, button_game_pins)
                ]

solved_moduli = []	

main_timer = Timer(period=50, mode=Timer.PERIODIC, callback=check)


while run:
	print('game is running...')
	mqtt_conn.check_msg()
	time.sleep(1)

print('Game over!')

for m in moduli_pool:
    m.deinit()
for m in solved_moduli:
    m.deinit()

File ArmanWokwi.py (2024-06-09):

from machine import ADC,Pin,Timer 
from utime import sleep
import random
import time
buttons =[Pin(0, Pin.IN),Pin(1, Pin.IN),Pin(2, Pin.IN),Pin(3, Pin.IN)]

gameStart=False ##SLUZI KO DEBOUNCER I ZNAMO KAD JE UPALJENA NEKA IGRA

##TIMER
##########################################################################################
pozicije=[Pin(4,Pin.OUT),Pin(5,Pin.OUT),Pin(6,Pin.OUT),Pin(7,Pin.OUT)]

pins = [
    Pin(8, Pin.OUT),  # A
    Pin(9, Pin.OUT),  # B
    Pin(10, Pin.OUT),  # C
    Pin(11, Pin.OUT),  # D
    Pin(12, Pin.OUT),  # E
    Pin(13, Pin.OUT),  # F
    Pin(14, Pin.OUT),  # G
    Pin(15,Pin.OUT)
]


digits = [
    [0, 0, 0, 0, 0, 0, 1,1], # 0
    [1, 0, 0, 1, 1, 1, 1,1], # 1
    [0, 0, 1, 0, 0, 1, 0,1], # 2 
    [0, 0, 0, 0, 1, 1, 0,1], # 3
    [1, 0, 0, 1, 1, 0, 0,1], # 4
    [0, 1, 0, 0, 1, 0, 0,1], # 5
    [0, 1, 0, 0, 0, 0, 0,1], # 6
    [0, 0, 0, 1, 1, 1, 1,1], # 7
    [0, 0, 0, 0, 0, 0, 0,1], # 8
    [0, 0, 0, 0, 1, 0, 0,1]  # 9
]
def postavi1(trenutni): # PALI A B C D E F G
    for j in range(len(pins)):
        pins[j].value(digits[trenutni][j])

def postavi(brojevi): # UGASI SVE PA POSTAVI SVAKI BROJ POJEDINACNO I UGASI
    for i in range(4):
        pozicije[i].on()
    for i in range(4):
        pozicije[i].off()
        postavi1(brojevi[i])
        sleep(0.02)
        pozicije[i].on()


def popravi(brojevi): # POPRAVLJA KAD SE SMANJUJE I POVECAVA BROJ
    for i in range(3,0,-1):
        if brojevi[i]>9:
            brojevi[i]=0
            brojevi[i-1]+=1
        else:
             break
    for i in range(3,0,-1):
        if brojevi[i]<0:
            brojevi[i]=9
            brojevi[i-1]-=1
        else:
            break
    if brojevi[0]<0:
        for i in range(4):
            brojevi[i]=9
    if brojevi[0]>9:
        for i in range(4):
            brojevi[i]=0
    return brojevi

brojevi=[0,0,0,0]
timer=Timer(-1) #TIMER ZA SAT
timer.deinit()
timerPrikazivanje=Timer(-1)
timerPrikazivanje.deinit()


def TimerOn():
    global timer,timerPrikazivanje
    timer.init(mode=Timer.PERIODIC, period=1000, callback=Odbrojavanje)
    timerPrikazivanje.init(mode=Timer.PERIODIC, period=500, callback=Prikaz) 
    ##NAMEJSTITI PERIOD DA LJEPSE ISPISUJE NA LED INDIKATORU ILI DODAVANJE SLEEP U POSTAVI

def TimerOff():
    global timer
    timer.deinit()
    timerPrikazivanje.deinit()
    postavi([0,0,0,0])

def Prikaz(tim):    ##PRIKAZUJE NA LED INDIKATORU
    global brojevi,timerPrikazivanje
    postavi(brojevi)

def Odbrojavanje(timer):    ##ODBROJAVA SEKUNDI PO SEKUND I UPDATE BROJEVI
    global brojevi,gameStart
    brojevi[3]-=1
    popravi(brojevi)
    if brojevi[0]==9:   ##KAD OD [0,0,0,0] ODUZMEMO 1 POPRAVI CE STAVITI [9,9,9,9]
        brojevi=[0,0,0,0]
        print("BOMBAAA")
        timer.deinit()
        timerPot.deinit()   #Gasi potenciometar games
        timerMat.deinit()   #Gasi matricna games
        gameStart=False

##PotenciometarGame
##########################################################################################
potenciometar=ADC(28)
sifra=0
timerPot=Timer(-1)  #TIMER ZA POTENCIOMETAR GAME
timerPot.deinit()

def PotenciometarGame(tim):
    global timer,sifra,gameStart,timerPot
    print(int(potenciometar.read_u16()/65535*100))
    if int(potenciometar.read_u16()/65535*100)==sifra:
        TimerOff()
        print("BRAVO NO BOMBA KAPUT ON POTENCIOMETAR GAME")
        timerPot.deinit()
        gameStart=False

def StartPotenciometarGame(irq):
    global timerPot,brojevi,sifra,gameStart
    if gameStart:
        return
    gameStart=True
    brojevi=[0,0,2,0] #Koliko vremena im daješ
    sifra=random.randrange(0,100)
    print("PODESI VRIJEDNOST POTENCIOMETRA NA TRAŽENU")
    print("Šifra je "+str(sifra)) ##KASNIJE POSLATI  DRUGOM IGRAČU
    TimerOn()
    timerPot.init(mode=Timer.PERIODIC, period=1000, callback=PotenciometarGame)

##MATRICNII
##########################################################################################
izlazMatricna = [ Pin(26 ,Pin.OUT),Pin(22 ,Pin.OUT),Pin(21 ,Pin.OUT),Pin(20 ,Pin.OUT) ] 
ulazMatricna = [ Pin(i, Pin.IN, Pin.PULL_DOWN) for i in range(19, 15,-1)]

cifra = [
  [ 1, 2, 3, 'A' ],
  [ 4, 5, 6, 'B' ],
  [ 7, 8, 9, 'C' ],
  [ '*', 0, '#', 'D' ]
]

sifraMatricna=[0,0,0,0]
brojacMatricna=0
timerMat=Timer(-1)  #TIMER ZA POTENCIOMETAR GAME
timerMat.deinit()
korisnikSifra=[0,0,0,0]
brojevi=[0,0,2,0] #Koliko vremena im daješ
debounce=0

def generisiSifruMatricna():
    global sifraMatricna
    for i in range(3):
        sifraMatricna[i]=random.randrange(0,9)

def postaviSifru(irq):
    global sifraMatricna,izlazMatricna,ulazMatricna,korisnikSifra,brojacMatricna,gameStart,debounce
    if time.ticks_ms()-debounce<400:
        return
    for i in range(4):
        izlazMatricna[i].value(1)
        for j in range(4):
            if ulazMatricna[j].value() == 1:
                izlazMatricna[i].value(0)
                korisnikSifra[brojacMatricna] = cifra[i][j] 
                brojacMatricna+=1
                debounce=time.ticks_ms()
                print(cifra[i][j])         
        izlazMatricna[i].value(0)
    if sifraMatricna==korisnikSifra and brojacMatricna==4:
        TimerOff()
        print("BRAVO NO BOMBA KAPUT ON MATRCINA TASTATURA GAME")
        timerMat.deinit()
        korisnikSifra=[0,0,0,0]
        brojacMatricna=0
        debounce=0
        gameStart=False
        return
    if brojacMatricna==4:
        print("POGRESNA SIFRA")
        brojacMatricna=0
        korisnikSifra=[0,0,0,0]
    
def StartMatricnaGame(irq):
    global brojevi,timerMat,gameStart
    if gameStart:
        return
    gameStart=True
    generisiSifruMatricna()
    print("UKUCAJ ŠIFRU NA MATIČNOJ TASTATURI")
    print(sifraMatricna) ##KASNIJE POSLATI DRUGOM KORISNIKU SIFRU
    brojevi=[0,0,2,0] #Koliko vremena im daješ
    TimerOn()
    timerMat.init(mode=Timer.PERIODIC, period=50, callback=postaviSifru) ##Igrati se sa period

##LABIRINT (KORISTIMO DEKLARACIJE IZ PRETHODNE IGRICE)
##########################################################################################

labirintPut=[0,0,0,0,0,0,0,0] ##POGODITI 8 smjerova
brojacLabirint=0

def generisiPut():
    global labirintPut
    for i in range(8):
        labirintPut[i]=random.choice([2,4,6,8])
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

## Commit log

2024-06-09 Dodan debouncer u labirint i pin kod
2024-06-12 bug fix otkriven danas na matricnoj
    [matricna.py]
2024-06-22 Lijep tekst de nek neko doda jos ovo malo za 7segment i rgb
2024-06-22 ne mogu naci 7seg iz nekog razloga
    [Main.fzz]
2024-06-23 slave izsheman
    [slave.fzz]
2024-06-23 stavljam Pin.PULL_DOWN svugdje + promjena protokola
2024-06-26 1. konfigurisan lokalni broker 2. keepalive je 6 minuta na lokalnom brokeru dovoljno da mi konekcija ne umre! 3. Svi moduli moraju odsada imati metodu deinit koja samo gasi sve
    [main.py, main_slave.py]
2024-06-26 dobro pa sam testirao broker
    [main.py, main_slave.py]
